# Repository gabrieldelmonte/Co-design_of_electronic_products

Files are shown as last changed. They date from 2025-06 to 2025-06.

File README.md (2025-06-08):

# PBLE01 - Electronic Product Co-design Project

## Overview
This repository contains the complete design files and documentation for PBLE01 - Electronic Product Co-design, a university project developed at UNIFEI (Federal University of Itajubá). The project involves designing a custom printed circuit board (PCB) with microcontroller-based functionality, peripheral interfaces, and power management systems.

## Project Features
- **Microcontroller**: STM32F030K6T6TR (ARM Cortex-M0)
- **Power Supply**: 5V via USB-C with voltage regulation to 3.3V
- **Peripherals**:
  - LCD interface (16x2 character display)
  - 3-button tactile keyboard
  - Status LEDs
  - USB-Serial transceiver (MCP2200)
  - EEPROM memory (24LC512)
  - Light sensor (PDV-P8103 photoresistor)
- **Expansion Interfaces**:
  - SPI connector
  - I²C connector
  - General-purpose GPIO pins
- **Programming Interfaces**: SWD and UART
- **Safety Features**:
  - Overcurrent protection (PPTC fuse)
  - Reverse voltage protection
  - Power indication LEDs

## Technical Specifications
| Parameter | Value |
|---|---|
| PCB Dimensions | 70 × 70 mm |
| Layer Count | 2 (double-sided) |
| Signal Trace Width | ≥ 8 mils |
| Power Trace Width | ≥ 12 mils |
| Minimum Spacing | 8 mils |
| Minimum Via Diameter  | 12 mils |
| Operating Voltage | 5V DC (USB powered) |
| Voltage Regulation | 3.3V (LD1117S33TR)  |
| Microcontroller Clock | 8 MHz crystal |

## Repository Structure

```
├── Hardware/
│   └── Projeto_2022014552/ # Complete KiCad design files
├── Documentation/
│   ├── Manual.pdf          # Complete technical documentation
│   ├── Design_Guidelines.pdf
│   └── Requirements.pdf
└── Components/
    └── .../                # Components used in the project Kicad
```

## Design Tools
- **PCB Design**: KiCad v8.99
- **Documentation**: LaTeX/Overleaf
- **Simulation**: Not applicable (hardware-only project)

## Key Design Sections
1. **Power Subcircuit**  
   - USB-C input (USB4215-03-A)
   - Voltage regulation (LD1117S33TR)
   - Power indicators (5V/3.3V LEDs)

2. **Operation Subcircuit**  
   - STM32F030K6 microcontroller
   - 8MHz crystal oscillator
   - Boot mode selection

3. **Peripheral Subcircuit**  
   - USB-Serial interface (MCP2200)
   - EEPROM memory (24LC512)
   - Ambient light sensor (PDV-P8103)

4. **Expansion Interfaces**  
   - SPI (4-wire + power)
   - I²C (2-wire + power)
   - GPIO breakout

## Bill of Materials Highlights
| Component | Qty | Description |
|---|-----|---|
| STM32F030K6T6TR | 1 | ARM Cortex-M0 MCU |
| LD1117S33TR | 1 | 3.3V Voltage Regulator |
| MCP2200-I/SO | 1 | USB-UART Bridge |
| 24LC512-I/SN | 1 | 512KB EEPROM |
| PDV-P8103 | 1 | Photoresistor |
| USB4215-03-A | 1 | USB-C Connector |
| JHD162A | 1 | 16×2 LCD Display |
| 3296W-1-103RLF  | 1 | 10kΩ Trimmer |

## Design Validation
- Electrical Rule Check (ERC) passed in KiCad
- Design Rule Check (DRC) compliant with course requirements
- Power consumption analysis included
- Component placement optimized for signal integrity

## Academic Context
Developed for **PBLE01 - Electronic Product Co-design** (2024.2 Semester) at UNIFEI under Prof. Rodrigo de Paula Rodrigues. The project fulfills all course requirements specified in the design guidelines documentation.

## License
This project is for academic purposes. Component datasheets remain property of their respective manufacturers. Design files are provided as-is without warranty.

---

> **Note**: This design has NOT been manufactured yet. See project manual for validation reports and design analysis.

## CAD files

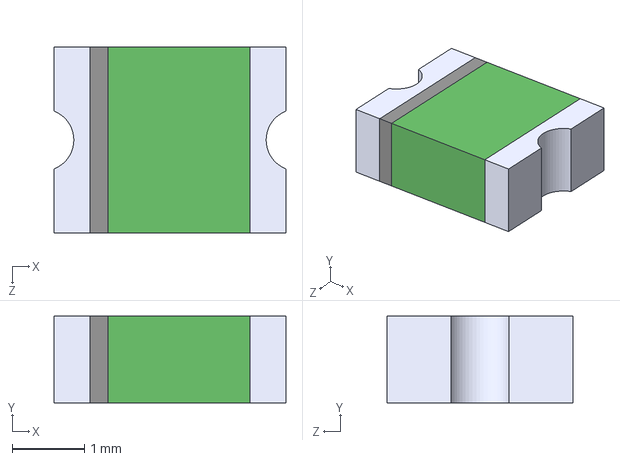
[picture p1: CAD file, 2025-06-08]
Components/0ZCH0050FF2G/0ZCH0050FF2G.step
3.22 x 1.20 x 2.58 mm

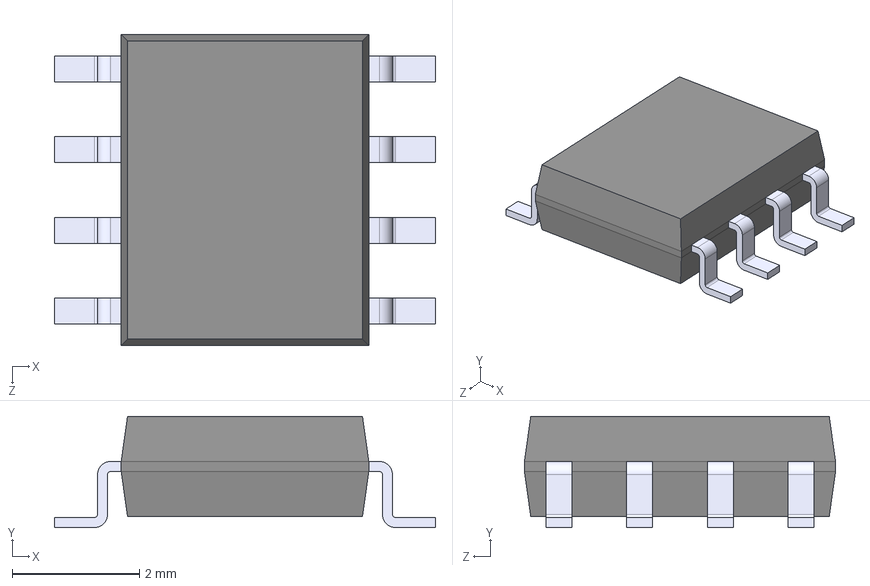
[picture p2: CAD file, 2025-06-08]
Components/24LC512-I_SMG/24LC512-I_SMG.step
6.00 x 1.75 x 4.90 mm

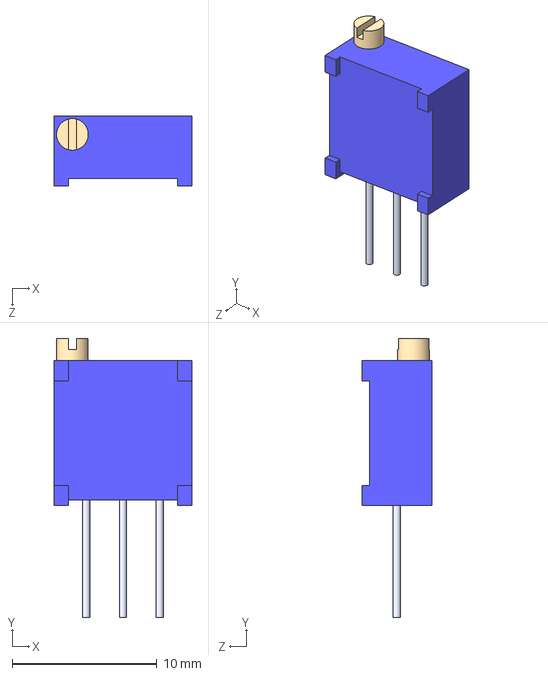
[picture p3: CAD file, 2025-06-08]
Components/3296W-1-103RLF/3296W-1-103RLF.step
9.53 x 19.3 x 4.83 mm

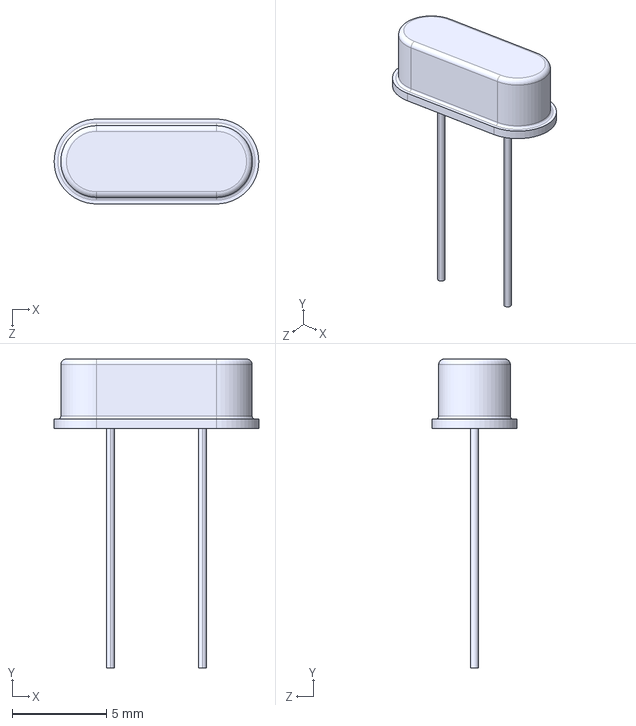
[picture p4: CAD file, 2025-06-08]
Components/ATS08A-E/ATS08A-E.step
10.9 x 16.4 x 4.50 mm

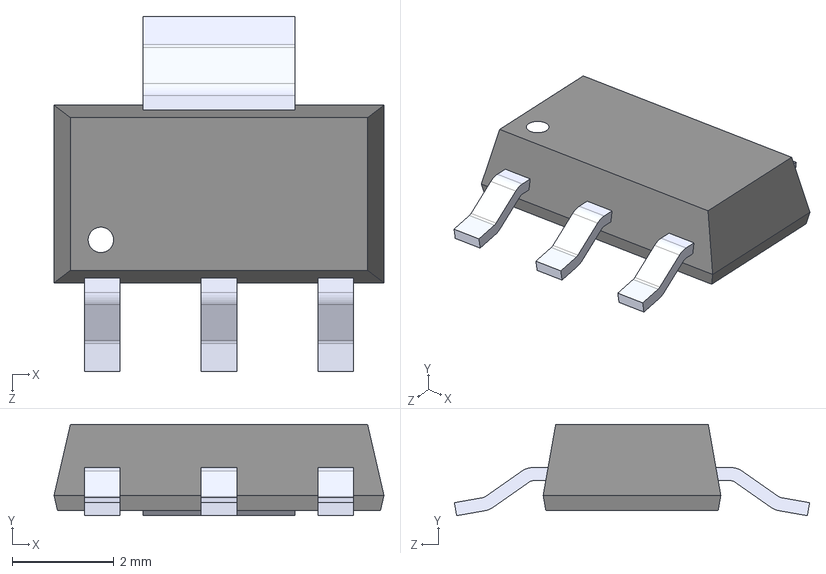
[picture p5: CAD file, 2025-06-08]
Components/LD1117S33TR/LD1117S33TR.step
6.50 x 1.80 x 7.00 mm

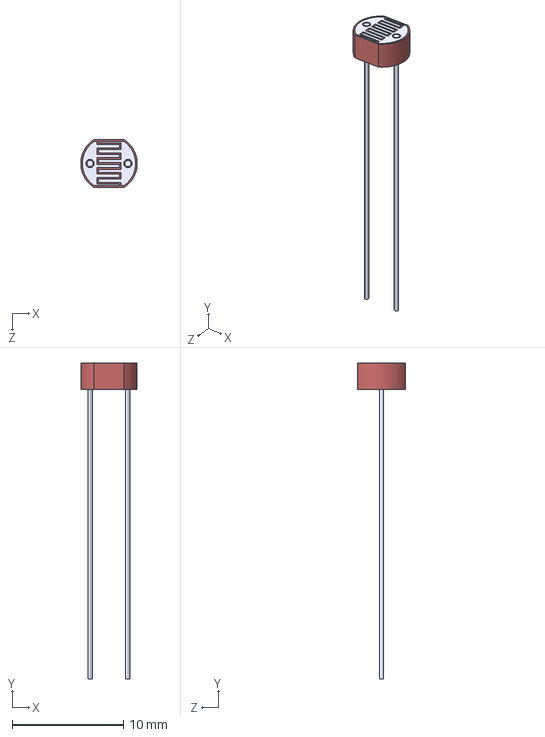
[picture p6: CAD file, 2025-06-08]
Components/PDV-P8103/PDV-P8103.step
5.07 x 28.4 x 4.29 mm

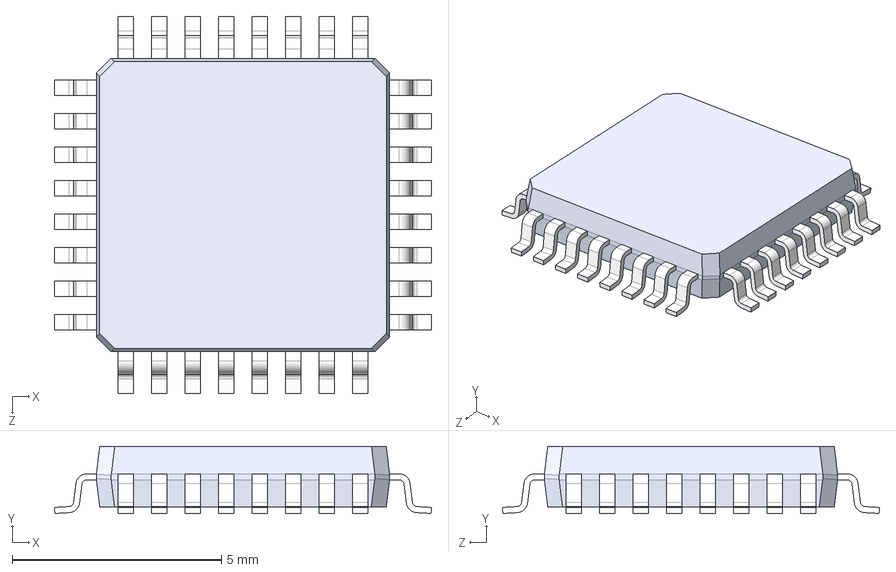
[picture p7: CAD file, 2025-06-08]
Components/STM32F030K6T6TR/STM32F030K6T6TR.step
9.00 x 1.60 x 9.00 mm

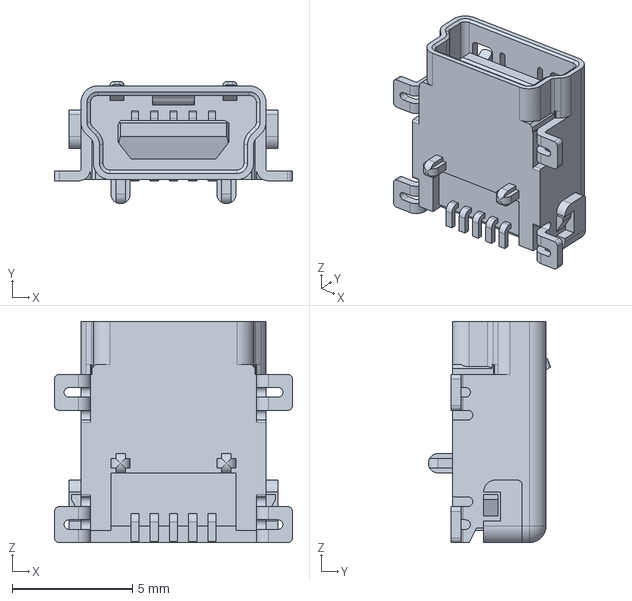
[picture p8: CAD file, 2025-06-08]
Components/1734035-2/1734035-2.step
9.90 x 5.09 x 9.20 mm

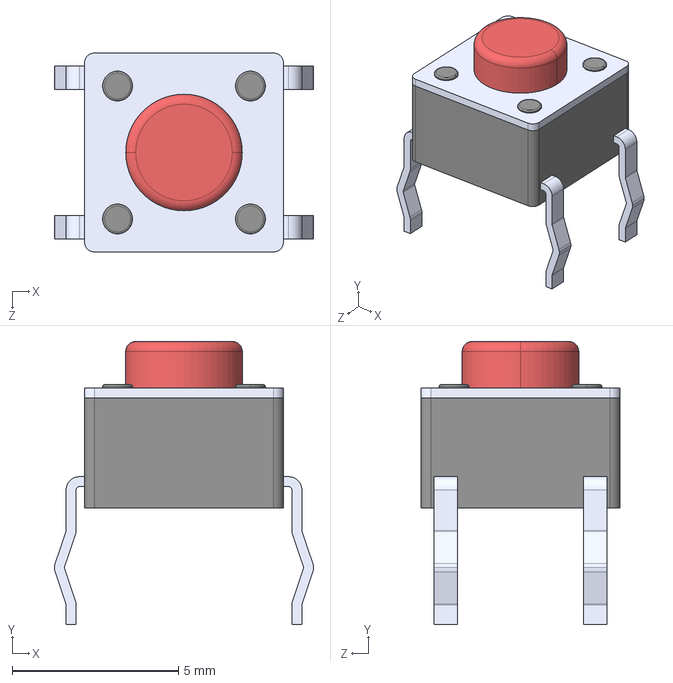
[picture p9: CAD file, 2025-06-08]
Components/1825910-6/1825910-6.step
7.80 x 8.52 x 5.99 mm

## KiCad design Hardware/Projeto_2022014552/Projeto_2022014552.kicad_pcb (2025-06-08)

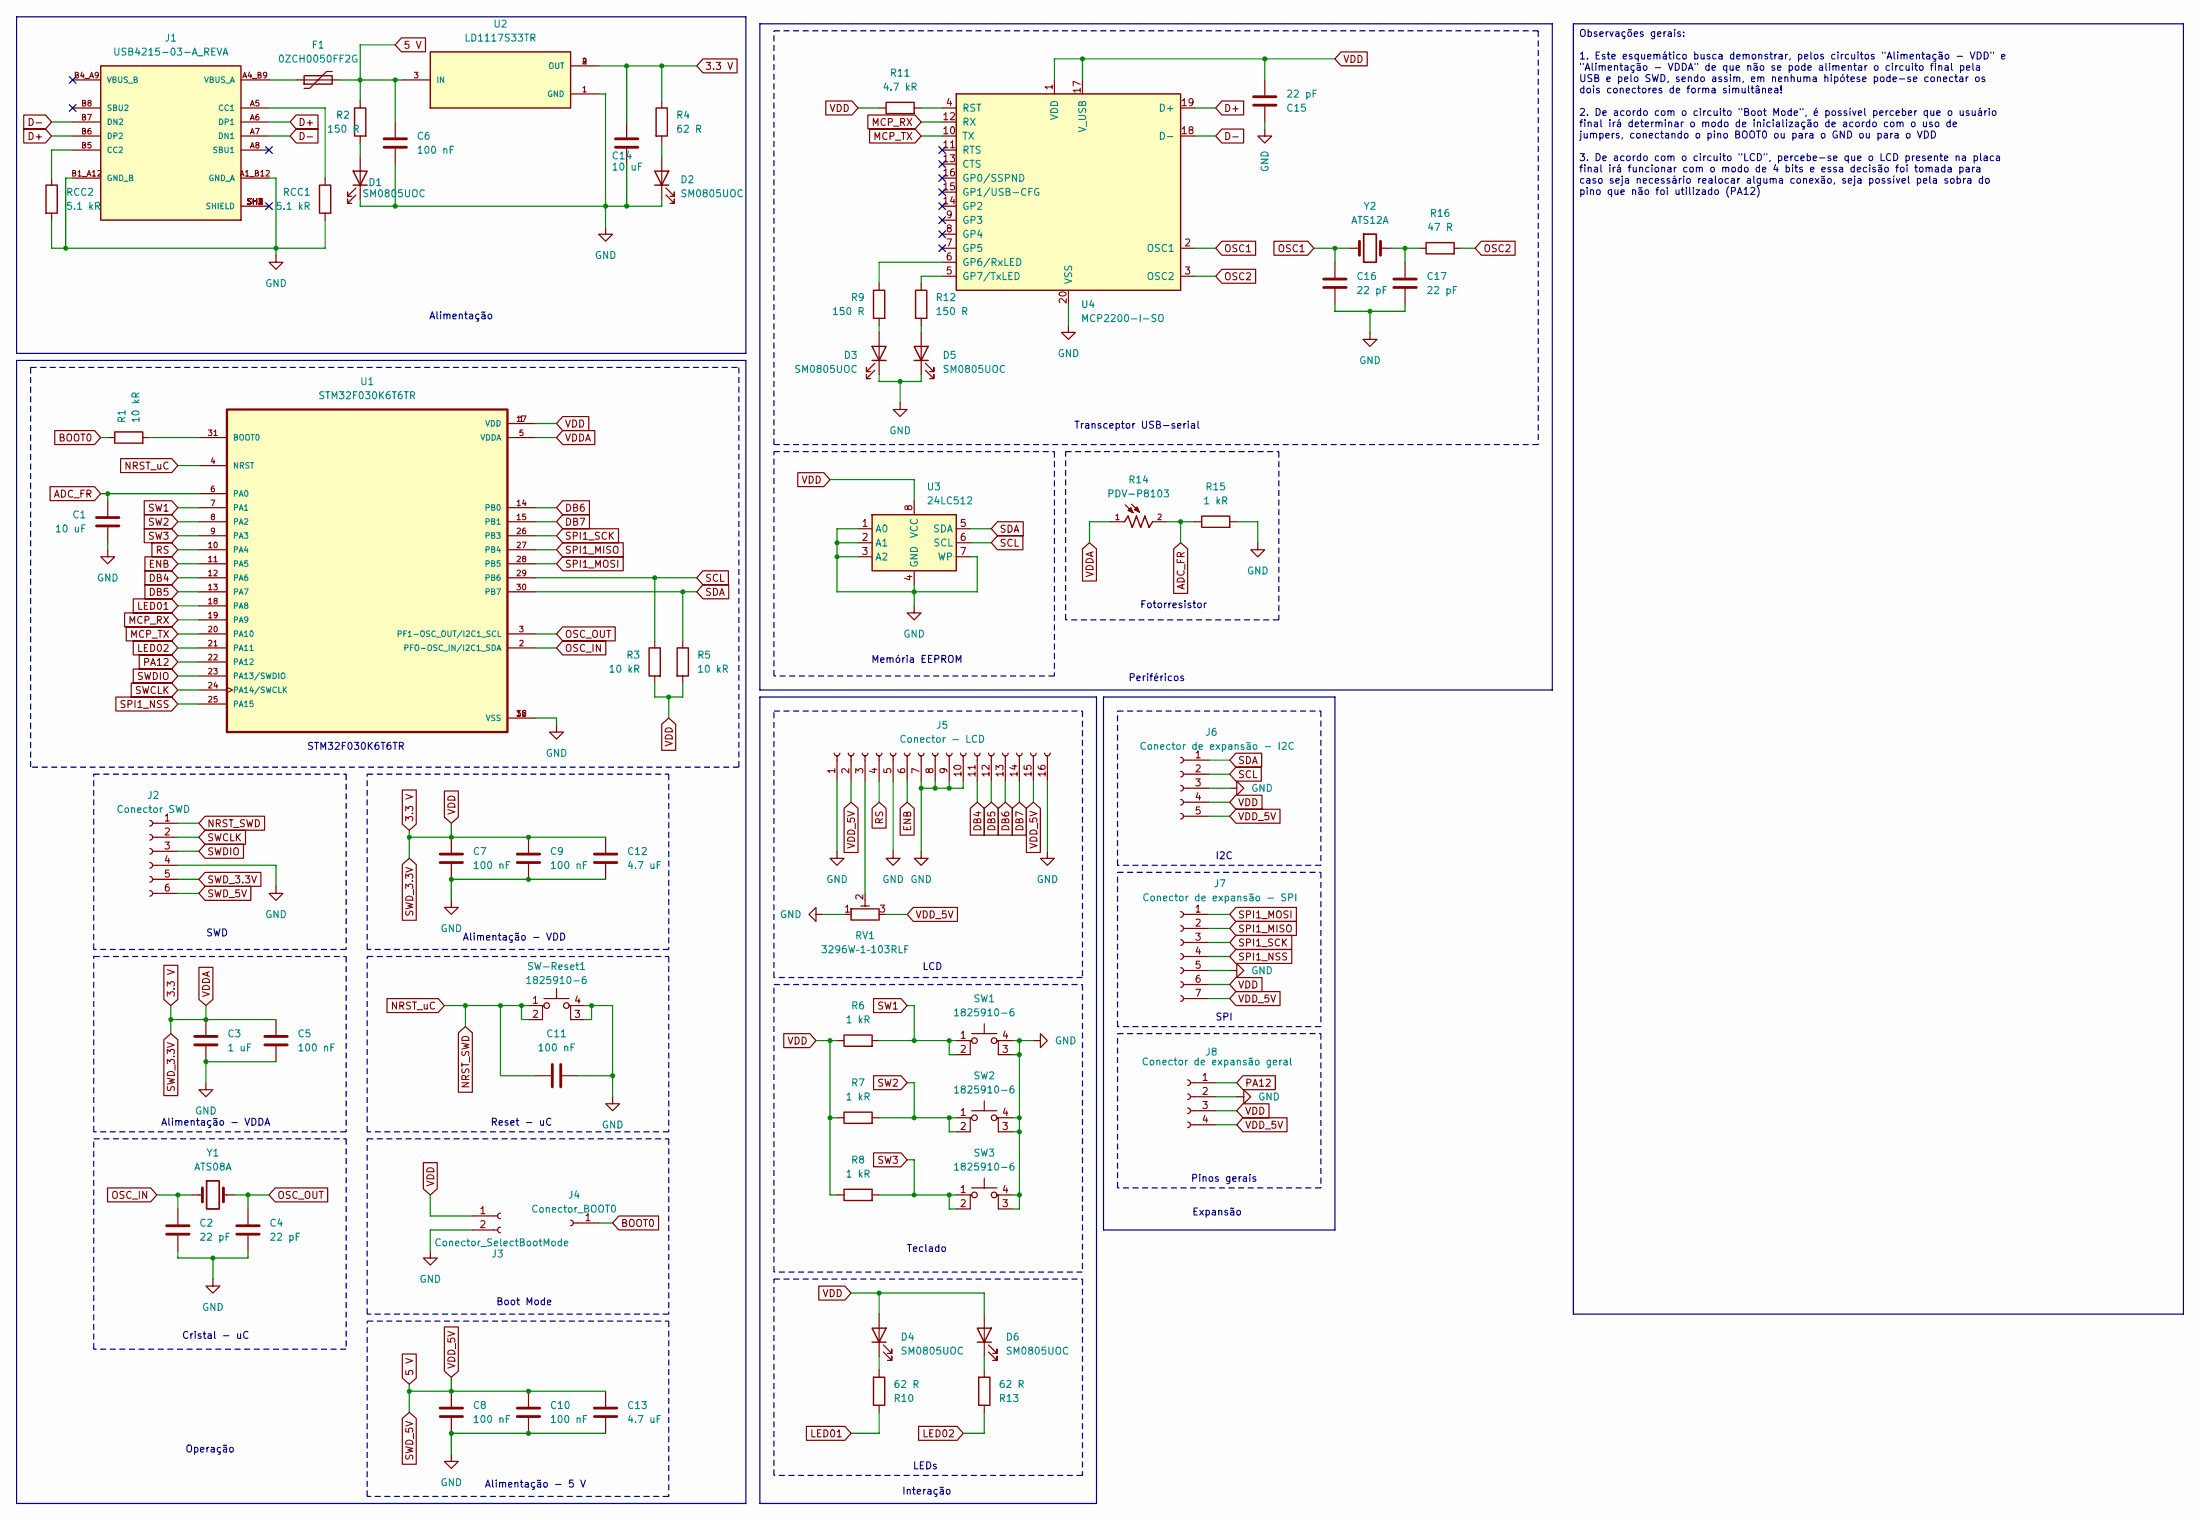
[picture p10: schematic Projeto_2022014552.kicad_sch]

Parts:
C1, C14: 10 uF; C_0805_2012Metric
C2, C4, C15, C16, C17: 22 pF; C_0805_2012Metric
C3: 1 uF; C_0805_2012Metric
C5, C6, C7, C8, C9, C10, C11: 100 nF; C_0805_2012Metric
C12, C13: 4.7 uF; C_0805_2012Metric
D1, D2, D3, D4, D5, D6: SM0805UOC
F1: 0ZCH0050FF2G; RESC3225X75N
J1: USB4215-03-A_REVA; GCT_USB4215-03-A_REVA; PARTREV A; DigiKey_Part_Number 2073-USB4215-03-ATR-ND
J2: Conector SWD; PinSocket_1x06_P2.54mm_Vertical
J3: Conector_SelectBootMode; PinSocket_1x02_P2.54mm_Vertical
J4: Conector_BOOT0; PinSocket_1x01_P2.54mm_Vertical
J5: Conector - LCD; PinSocket_1x16_P2.54mm_Vertical
J6: Conector de expansão - I2C; PinSocket_1x05_P2.54mm_Vertical
J7: Conector de expansão - SPI; PinSocket_1x07_P2.54mm_Vertical
J8: Conector de expansão geral; PinSocket_1x04_P2.54mm_Vertical
R1, R3, R5: 10 kR; R_0805_2012Metric
R2, R9, R12: 150 R; R_0805_2012Metric
R4, R10, R13: 62 R; R_0805_2012Metric
R6, R7, R8, R15: 1 kR; R_0805_2012Metric
R11: 4.7 kR; R_0805_2012Metric
R14: PDV-P8103; PHODET_PDV-P8103; PARTREV 3/30/06
R16: 47 R; R_0805_2012Metric
RCC1, RCC2: 5.1 kR; R_0805_2012Metric
RV1: 3296W–1–103RLF; TRIM_3296W-1-103RLF
SW1, SW2, SW3: 1825910-6; SW_1825910-6-4
SW-Reset1: 1825910-6; SW_1825910-6-4
U1: STM32F030K6T6TR; QFP80P900X900X160-32N; PARTREV 3
U2: LD1117S33TR; SOT230P700X180-4N
U3: 24LC512; SOIC127P794X203-8N
U4: MCP2200-I-SO; SOIC20
Y1: ATS08A; XTAL_HC49P488W43L1085T450H368
Y2: ATS12A

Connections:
3.3 V: C3.1, C5.1, C7.1, C9.1, C12.1, C14.2, C15.2, D4.2 (A), D6.2 (A), J2.5, J3.1, J6.4, J7.6, J8.3, R3.2, R4.1, R5.2, R6.1, R7.1, R8.1, R11.1, R14.1, U1.1 (VDD), U1.5 (VDDA), U1.17 (VDD), U2.2 (OUT), U2.4 (OUT), U3.8 (VCC), U4.1 (VDD), U4.17 (V_USB)
5 V: C6.1, C8.1, C10.1, C13.1, F1.2, J2.6, J5.2, J5.15, J6.5, J7.7, J8.4, R2.1, RV1.3, U2.3 (IN)
ADC_FR: C1.1, R14.2, R15.1, U1.6 (PA0)
BOOT0: J4.1, R1.1
D+: J1.A6 (DP1), J1.B6 (DP2), U4.19 (D+)
D-: J1.A7 (DN1), J1.B7 (DN2), U4.18 (D-)
DB4: J5.11, U1.12 (PA6)
DB5: J5.12, U1.13 (PA7)
DB6: J5.13, U1.14 (PB0)
DB7: J5.14, U1.15 (PB1)
ENB: J5.6, U1.11 (PA5)
GND: C1.2, C2.2, C3.2, C4.2, C5.2, C6.2, C7.2, C8.2, C9.2, C10.2, C11.2, C12.2, C13.2, C14.1, C15.1, C16.2, C17.2, D1.1 (K), D2.1 (K), D3.1 (K), D5.1 (K), J1.A1_B12 (GND_A), J1.B1_A12 (GND_B), J2.4, J3.2, J5.1, J5.5, J5.7, J5.8, J5.9, J5.10, J5.16, J6.3, J7.5, J8.2, R15.2, RCC1.2, RCC2.2, RV1.1, SW1.3 (K), SW1.4 (A), SW2.3 (K), SW2.4 (A), SW3.3 (K), SW3.4 (A), SW-Reset1.3 (K), SW-Reset1.4 (A), U1.16 (VSS), U1.32 (VSS), U2.1 (GND), U3.1 (A0), U3.2 (A1), U3.3 (A2), U3.4 (GND), U3.7 (WP), U4.20 (VSS)
LED01: R10.1, U1.18 (PA8)
LED02: R13.1, U1.21 (PA11)
MCP_RX: U1.19 (PA9), U4.12 (RX)
MCP_TX: U1.20 (PA10), U4.10 (TX)
NRST_SWD: C11.1, J2.1, SW-Reset1.1, SW-Reset1.2, U1.4 (NRST)
unnamed: C17.1, R16.1, Y2.2
unnamed: D1.2 (A), R2.2
unnamed: D2.2 (A), R4.2
unnamed: D3.2 (A), R9.2
unnamed: D4.1 (K), R10.2
unnamed: D5.2 (A), R12.2
unnamed: D6.1 (K), R13.2
unnamed: J1.A5 (CC1), RCC1.1
unnamed: J1.B5 (CC2), RCC2.1
unnamed: F1.1, J1.A4_B9 (VBUS_A)
unnamed: J5.3, RV1.2
unnamed: R1.2, U1.31 (BOOT0)
unnamed: R9.1, U4.6 (GP6/RxLED)
unnamed: R12.1, U4.5 (GP7/TxLED)
unnamed: R11.2, U4.4 (RST)
OSC1: C16.1, U4.2 (OSC1), Y2.1
OSC2: R16.2, U4.3 (OSC2)
OSC_IN: C2.1, U1.2 (PFO-OSC_IN/I2C1_SDA), Y1.1
OSC_OUT: C4.1, U1.3 (PF1-OSC_OUT/I2C1_SCL), Y1.2
PA12: J8.1, U1.22 (PA12)
RS: J5.4, U1.10 (PA4)
SCL: J6.2, R3.1, U1.29 (PB6), U3.6 (SCL)
SDA: J6.1, R5.1, U1.30 (PB7), U3.5 (SDA)
SPI1_MISO: J7.2, U1.27 (PB4)
SPI1_MOSI: J7.1, U1.28 (PB5)
SPI1_NSS: J7.4, U1.25 (PA15)
SPI1_SCK: J7.3, U1.26 (PB3)
SW1: R6.2, SW1.1, SW1.2, U1.7 (PA1)
SW2: R7.2, SW2.1, SW2.2, U1.8 (PA2)
SW3: R8.2, SW3.1, SW3.2, U1.9 (PA3)
SWCLK: J2.2, U1.24 (PA14/SWCLK)
SWDIO: J2.3, U1.23 (PA13/SWDIO)

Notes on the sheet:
SPI
Expansão
Alimentação - VDDA
Memória EEPROM
Boot Mode
Alimentação
Operação
Interação
Pinos gerais
Transceptor USB-serial
Teclado
STM32F030K6T6TR
I2C
Fotorresistor
Cristal - uC
Periféricos
LEDs
Reset - uC
Alimentação - 5 V
SWD
LCD
Alimentação - VDD
Observações gerais: 1. Este esquemático busca demonstrar, pelos circuitos "Alimentação - VDD" e "Alimentação - VDDA" de que não se pode alimentar o circuito final pela USB e pelo SWD, sendo assim, em nenhuma hipótese pode-se conectar os dois conectores de forma simultânea! 2. De acordo com o circui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

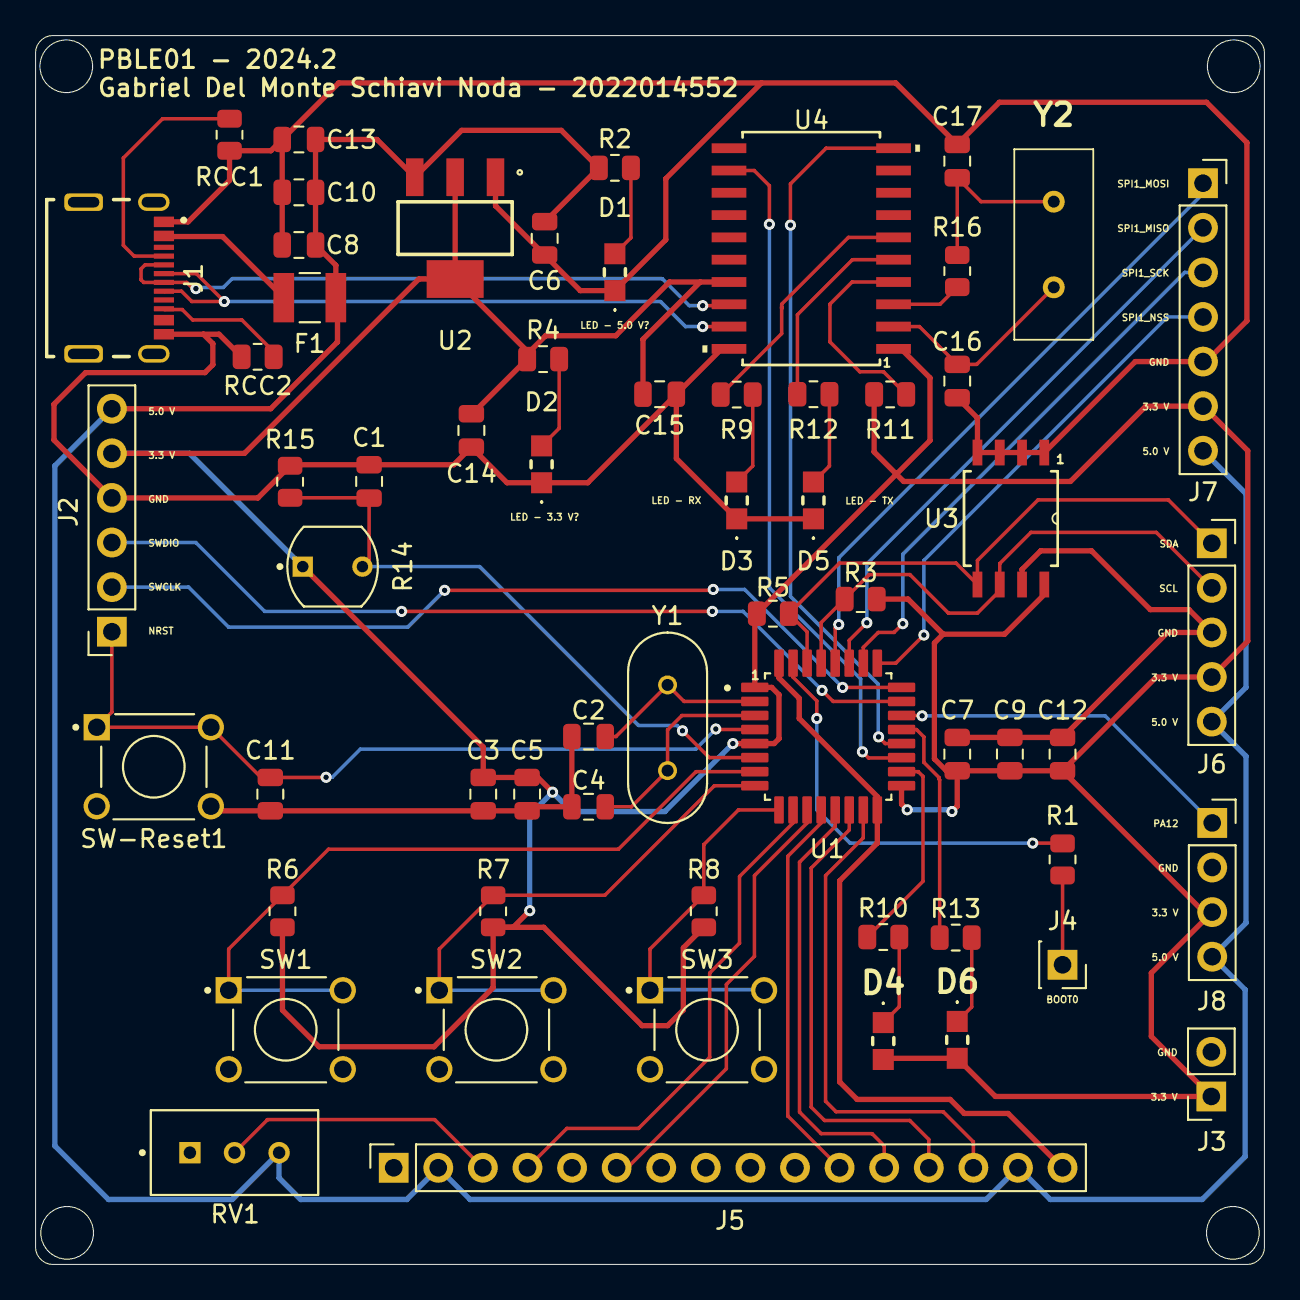
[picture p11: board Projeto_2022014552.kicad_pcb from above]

Board: 2 copper layers, 70.0 x 70.0 mm, 61 parts (0 on the bottom side), 49 nets.
